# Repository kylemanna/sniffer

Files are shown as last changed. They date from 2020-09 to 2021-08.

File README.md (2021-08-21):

# Sniffer



Air quality sensor integration board that couples together the following modules:

- ESP32 TTGO T-Display module
- PMSA003 module
- BME680 CJMCU module

I use this to track the AQI in my home.  This sensor measures within 1% of 3x different [PurpleAir sensors
scattered around my
neighborhood](https://www.purpleair.com/map?opt=1/i/mAQI/a10/cC0#12.69/37.74937/-122.43828).  The PMSA003 particulate air sensor module in this build should be an
improved version the PMS5003 found in the [PurpleAir
sensors](https://www2.purpleair.com/collections/air-quality-sensors).

Combined with [Home Assistant](https://www.home-assistant.io/), [InfluxDB](https://www.influxdata.com/),
and [Grafana](https://grafana.com/) I can track the long term air quality inside and outside my home.

## Details

* [Blog post with more details](https://blog.kylemanna.com/hardware/sniffer-air-quality-monitor-aqi-using-esp32-pmsa003-bme680/)

## Order PCBs

Want to build one?

[Visit the shared project on PCBWay for direct ordering](https://www.pcbway.com/project/shareproject/Sniffer_Air_Quality_Monitor.html).

## Early PCB Assembly

Sniffer LCD Display

[Google Photos Image
Gallery](https://photos.google.com/share/AF1QipN3LYySqBTejioxieJ7yeqid8oVPh8rAkidfJqBqCnVjT7ktObNcwMXL6851PJW0A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)

## TODO

### Hardware

- [x] Design Kicad schematic + PCB
- [x] Release Gerbers
- [x] Order PCBs from [PCBWay (use my referral code "3549" to save $5)](https://www.pcbway.com/setinvite.aspx?inviteid=3549)
- [x] Photograph real PCB + PCBA

- [ ] Add pin labels to silk screen
- [ ] Route out hole for TTGO T-Display battery connector so it fits flatter
- [ ] Find someone to make a 3D printable enclosure

### Software

- [x] Upload ESPHome YAML file

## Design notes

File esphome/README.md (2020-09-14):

# ESPHome

ESPHome works great on the TTGO ESP32 T-Display and has drivers for all the necessary pieces.  Connect it
to HomeAssistant and let HomeAssistant log to InfluxDB and visualize long-term data with Grafana.

## Building And Flashing the Unit

### Step 1: Launch ESPHome Docker container with USB support

    docker run --name esphome --rm -it --network host --privileged -v /dev:/dev -v $PWD:/config esphome/esphome

Display support was added in ESPHome v1.15.0, but if you need dev features (docs at [next.esphome.io](https://next.esphome.io/)):

    docker run --name esphome --rm -it --network host --privileged -v /dev:/dev -v $PWD:/config esphome/esphome:dev

### Step 2: Load Web UI

Should be http://localhost:6052 by default

### Step 3: Create

Copy contents of `sniffer.template.yaml` into ESPHome `sniffer0.yaml` or similar.

Update the secrets file appropriately or use the provided template as a starting point.

### Step 4: Flash ESP32

Attach to USB port of system running the ESP32 Docker container and Upload the newly created config.

### Step 5: Iterations

Now you can run the Docker container without `--privileged -v /dev:/dev` as the over-the-air update will
work.

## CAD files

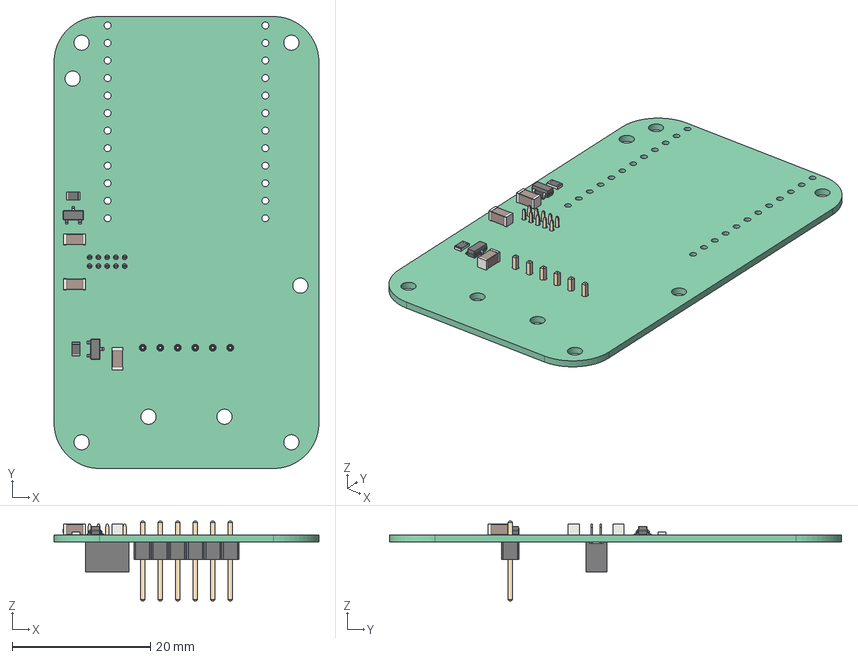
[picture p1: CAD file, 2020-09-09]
kicad/mechanicals/sniffer.step
38.4 x 65.5 x 11.5 mm
Local_CS_cf72
Pcb_cf72
PCB_Sketch_cf72
C1_C_1206_3216Metric_5F537C55
C2_C_1206_3216Metric_5F537BB3
C3_C_1206_3216Metric_5F537BE3
Q1_SOT_23_5F5360C2
Q2_SOT_23_5F537B45
R1_R_0805_2012Metric_5F53A661
R2_R_0805_2012Metric_5F537C13
J1_PinHeader_1x06_P254mm_Vertical_5F53974B
J2_PinSocket_2x05_P127mm_Vertical_5F536015

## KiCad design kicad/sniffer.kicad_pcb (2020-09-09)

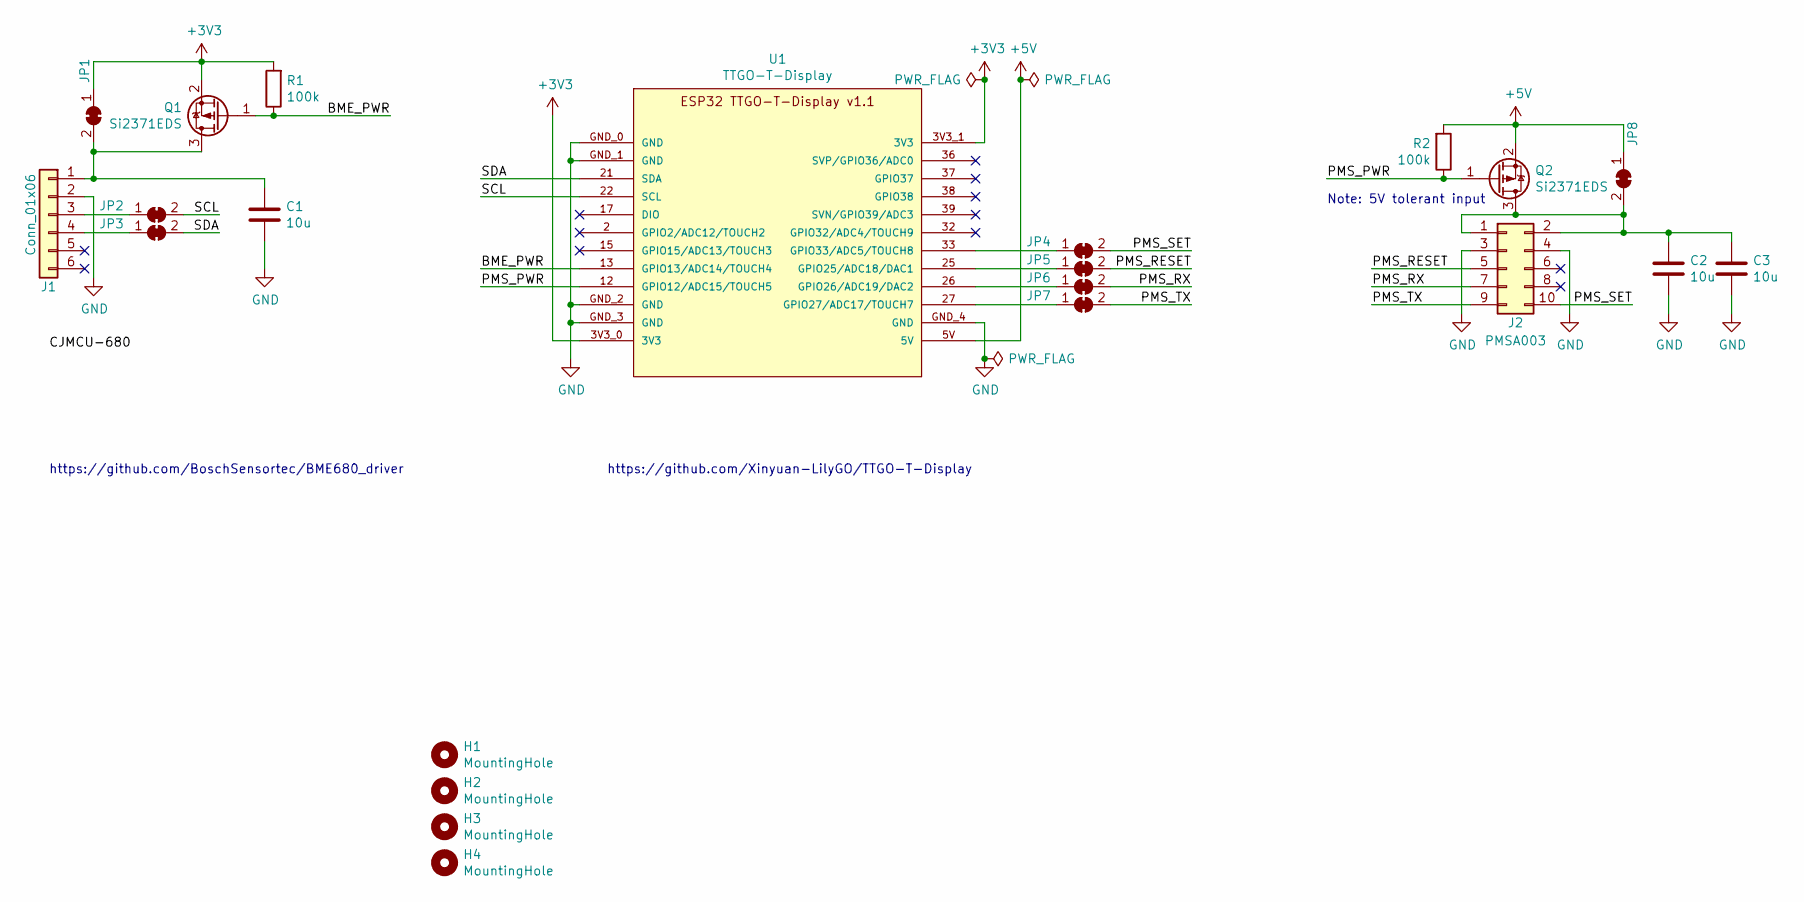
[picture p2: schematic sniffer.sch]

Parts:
C1, C2, C3: 10u; C_1206_3216Metric_Pad1.42x1.75mm_HandSolder
H1, H2, H3, H4: MountingHole; MountingHole_2.2mm_M2
J1: Conn_01x06; CJMCU-680
J2: PMSA003
JP1, JP2, JP3, JP4, JP5, JP6, JP7, JP8: SolderJumper_2_Bridged; SolderJumper-2_P1.3mm_Bridged_RoundedPad1.0x1.5mm
Q1, Q2: Si2371EDS; SOT-23
R1, R2: 100k; R_0805_2012Metric_Pad1.15x1.40mm_HandSolder
U1: TTGO-T-Display; TTGO-T-DISPLAY-OL-2

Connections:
+3V3: JP1.1 (A), Q1.2 (S), R1.2, U1.3V3_0 (3V3), U1.3V3_1 (3V3)
+5V: JP8.1 (A), Q2.2 (S), R2.2, U1.5V
/BME_PWR: Q1.1 (G), R1.1, U1.13 (GPIO13/ADC14/TOUCH4)
/PMS_PWR: Q2.1 (G), R2.1, U1.12 (GPIO12/ADC15/TOUCH5)
/PMS_RESET: J2.5, JP5.2 (B)
/PMS_RX: J2.7, JP6.2 (B)
/PMS_SET: J2.10, JP4.2 (B)
/PMS_TX: J2.9, JP7.2 (B)
/SCL: JP2.2 (B), U1.22 (SCL)
/SDA: JP3.2 (B), U1.21 (SDA)
GND: C1.2, C2.2, C3.2, J1.2, J2.3, J2.4, U1.GND_0 (GND), U1.GND_1 (GND), U1.GND_2 (GND), U1.GND_3 (GND), U1.GND_4 (GND)
unnamed: C1.1, J1.1, JP1.2 (B), Q1.3 (D)
unnamed: C2.1, C3.1, J2.1, J2.2, JP8.2 (B), Q2.3 (D)
unnamed: J1.3, JP2.1 (A)
unnamed: J1.4, JP3.1 (A)
unnamed: JP4.1 (A), U1.33 (GPIO33/ADC5/TOUCH8)
unnamed: JP5.1 (A), U1.25 (GPIO25/ADC18/DAC1)
unnamed: JP6.1 (A), U1.26 (GPIO26/ADC19/DAC2)
unnamed: JP7.1 (A), U1.27 (GPIO27/ADC17/TOUCH7)

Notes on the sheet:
https://github.com/Xinyuan-LilyGO/TTGO-T-Display
https://github.com/BoschSensortec/BME680_driver
Note: 5V tolerant input

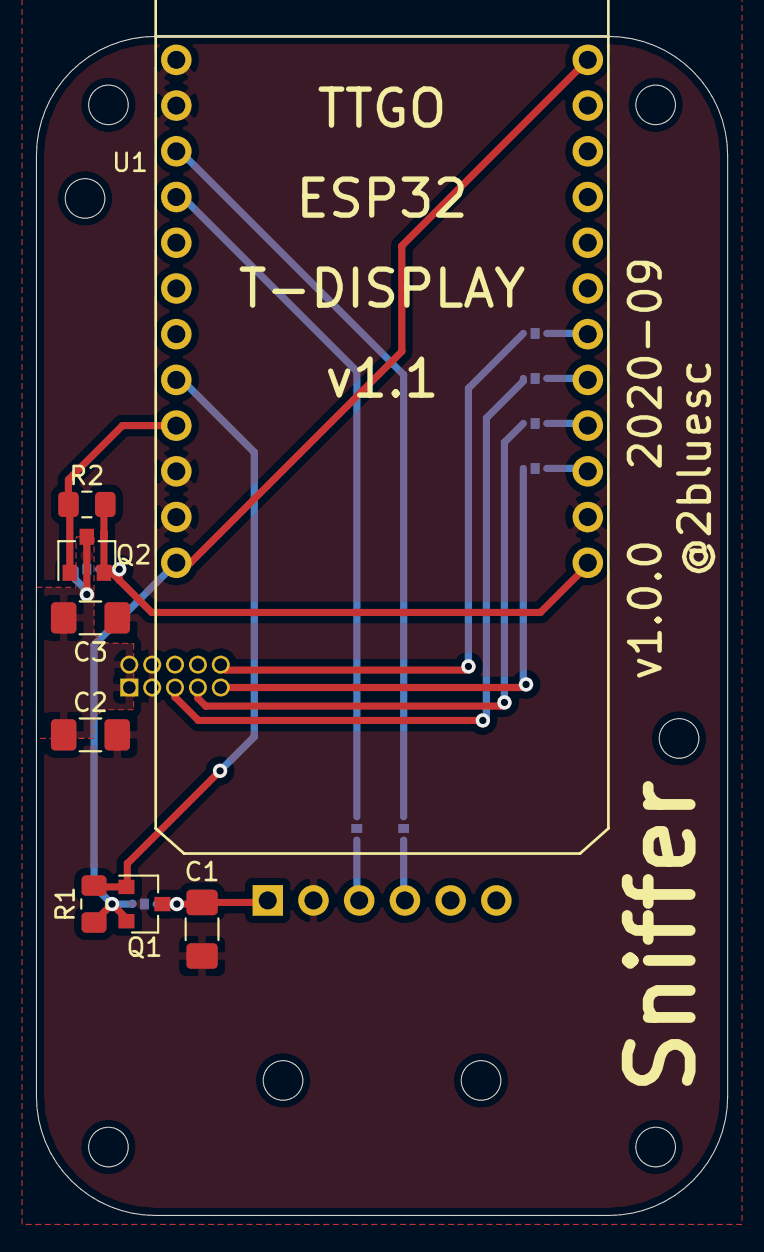
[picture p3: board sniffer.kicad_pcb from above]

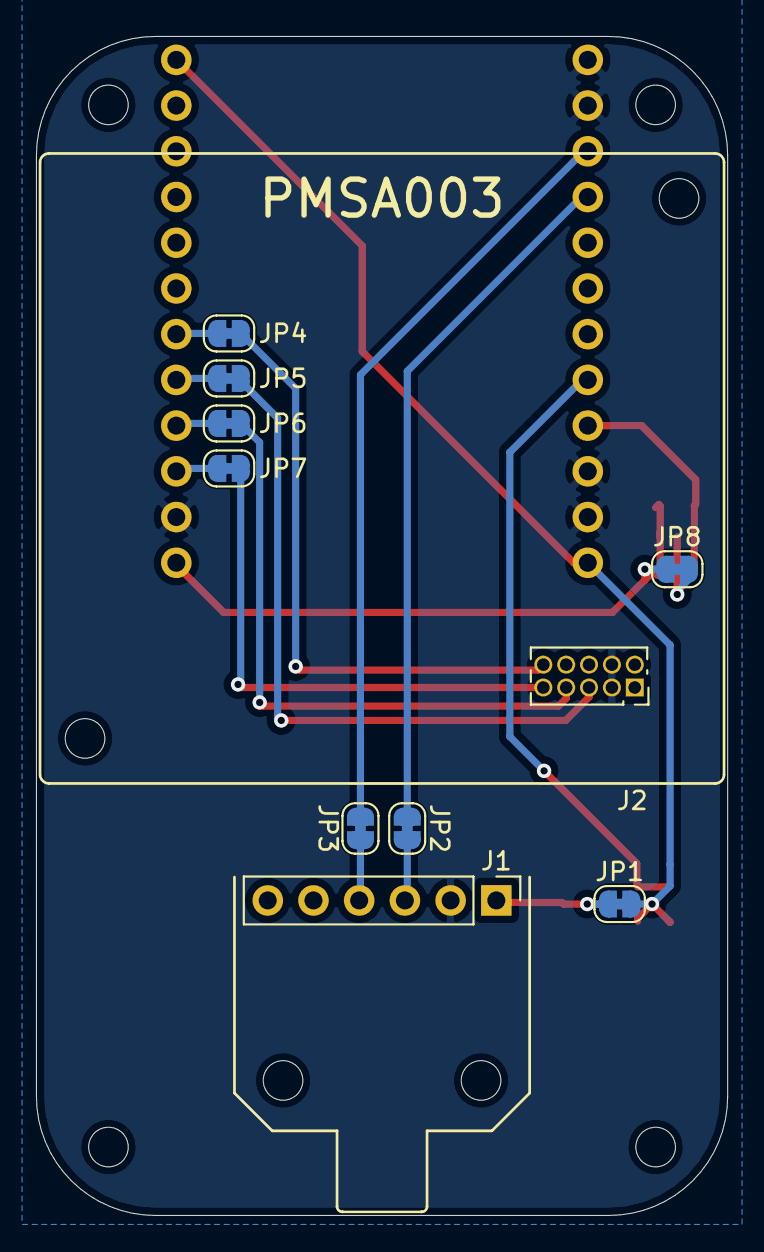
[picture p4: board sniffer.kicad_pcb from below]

Board: 2 copper layers, 38.4 x 65.5 mm, 22 parts (10 on the bottom side), 19 nets.

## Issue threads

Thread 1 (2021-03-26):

TTGO and PCB spacing

mckochan, 2021-03-26:
To anyone that has assembled one of these:
From the pictures, it looks like the TTGO either didn't have the battery connector or you removed it to allow the boards to sit close enough to use just the spacers on the male header pins?

Is there spacers available that I can use to raise the TTGO or does the battery connector removed easily?

Thanks in advance for this awesome project!

kylemanna, 2021-03-26:
I mounted the headers so they are slightly raised above the PCB to clear the battery connector.

For example if you took something small (toothpicks?) and put it in under the headers when you solder the 0.1" headers it'll solve the problem. Remove the toothpick (or whatever) after soldering.  I think I actually use a spare PCB from one side to hold the header at a consistent height.

See picture:
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

mckochan, 2021-03-26:
AH toothpick, genius! Thanks

Closed 2021-03-26.

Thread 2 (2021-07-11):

High temp value

Ralphy140, 2021-07-11:
comparing the value of other sensors sitting next to the Sniffer they seem to over read by 2-3C I suspect that this might be caused by the internal VOC sensor being on all the time as opposed to taking a sample every 60 seconds though i may be wrong.

In regards to the VOC and Air quality i have also found this that indicates how to extract the Bosch drivers to derive the VOC air quality

https://community.bosch-sensortec.com/t5/MEMS-sensors-forum/BME680-on-ESPHome-using-Bosch-s-BSEC-library/td-p/13210

I am no programmer but perhaps this could be updated into the code?

kylemanna, 2021-07-13:
I've noticed this as well and fear it may be higher then 3°C and have observed the same with the BME280 (no VOC sensor). I think it's actually being heated by the ESP32 through the pins.

I think the proper solution is to better isolate the BME680/280 better with a thermal PCB cutout or an external temp sensor like the [DS18B20](https://esphome.io/components/sensor/dallas.html?highlight=ds18b20)

I think the best workaround for this is to modify the esphome yaml code to provide a filter to subtract a 3°C offset or a more advanced function as I'm sure it's not a constant temperature offset.

Here's some documentation if you want to give it a try:
https://esphome.io/components/sensor/index.html#sensor-filters

Another option may be to reduce the power consumption of the ESP32 so it generates less heat, but I haven't looked to that yet.

Let me know if you get a chance to experiment with it!

kylemanna, 2021-07-13:
Another experiment would be to remove the BME680 from the pin headers and to attach it using wires that provide a poor thermal conduction path to see if this validates the idea.

Ralphy140, 2021-07-13:
Hey,

I have updated the YAML to make the required changes to take advantage of the VOC components and also reduce the temp by 3C, Happy to make a pull request or send it thought to you if you would like?

Ralphy140, 2021-07-13:
Also it seems odd that it exactly 3C across your ones and the 3 that i have made,

Ralphy140, 2021-07-16:
Pull request created to update temp off-set and BME680 driver

Closed 2021-07-16.

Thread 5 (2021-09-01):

Header for PMSA003

victorhooi, 2021-09-01:
I'm trying to locate an appropriate PMSA003 module to build this project.

In your [blog post](https://blog.kylemanna.com/hardware/sniffer-air-quality-monitor-aqi-using-esp32-pmsa003-bme680/
), you mention that the headers should be included with the modules, which you then solder to the PCB

I'm looking at some examples of the module (e.g. [here](https://www.aliexpress.com/item/32791143314.html
) and [here](https://www.aliexpress.com/item/32820384671.html)), and it's not always clear if the header is included.

Do you know of any reputable vendors that have the module with header? Or if not, where can you get the header from?

Ralphy140, 2021-09-01:
This one ships with the headers, the little black box with pins.

https://www.aliexpress.com/item/33024273311.html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

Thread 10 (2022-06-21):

TTGO chip update

larrygoodstuff, 2022-06-21:
It looks like the TTGO boards with a CP2104 chips are no longer available. They are only now available with a CH9102F chip. After successfully putting one together 1+ years ago, I decided to do another 4 and bought the components. After soldering them together and powering up I just get an "SDcard mount fail" error.

Will the pinouts need to change with the updated chip?

Awesome little project by the way.

hexonMD, 2024-01-20:
I ended up doing the same thing :(

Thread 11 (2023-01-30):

How do I upload the files to the TTGO?

zirdum, 2023-01-30:
Are there instructions on how to upload the yaml to the TTGO device?

Ralphy140, 2023-01-30:
This project uses ESPHome - https://esphome.io/ check out the getting started on the home page, It works really well with Home Assistant and would recommend you read up on that to get started.

Just to be clear you dont "upload" the YMAL to the device, you use a tool called ESP home that turns the YAML into a compiled file that is then uploaded to the esp32, you never upload the yaml directly to the device, if you want to change it you need to re-complie it in esphome then re-upload the file

zirdum, 2023-01-31:
Thank you. I figured out how to compile the yaml and uploaded it successfully to the ESP32.

Closed 2023-01-31.

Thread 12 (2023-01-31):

Pin connections between ESP32 and PMSA003

zirdum, 2023-01-31:
Hi,

I don't have the PCB yet, but I wanted to connect what I have to test things out first.

I have the esp32 wired to the PMSA003 with a G7-G135 connector in between (to make it easier to connect the wires)... I'm hoping it should work, but I can only go off of what the picture shows and it's very blurry (and I don't know how to read the schematics yet).

The G7-G135 adapter connected to the PMSA003 shows the wiring to be:
nc
nc
rst
tx
rx
set
gnd
vcc

With the power connector facing the left side (when looking at the esp32 and the display), I can see the vcc goes to the 1st pin on the bottom left of the ESP32 (5V), gnd goes to the 2nd pin from the bottom left (G) and I think set goes to the 3rd pin from the bottom left (pin 27). But it seems there are 2 pins from the PMSA003 are connected to each other perhaps (or do they go somewhere on the ESP32)?

Thank you.
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

Closed 2023-02-01.

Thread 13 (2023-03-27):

RecursionError: maximum recursion depth exceeded while calling a Python object

PureRandomGit, 2023-03-27:
When I run `esphome run sniffer0.yaml` I get this error: `RecursionError: maximum recursion depth exceeded while calling a Python object`. I have done all the steps as you have instructed in the README but it still doesn't work I have tried this on windows and Linux but to no avail. I also tried using the web UI, the manual installation, and ESPhome in homeassistant but none worked.

PureRandomGit, 2023-03-29:
The problem was solved by trying a fresh install and by using esphome through the command line. For anyone else having problems installing/compiling this first make sure that the esp board is flashed with the correct drivers, then if you receive an error about font or temp2 comment out the font and display section in sniffer_common (this makes the screen useless but I couldn't figure out what was wrong, if someone knows please let me know.)

Closed 2023-03-29.

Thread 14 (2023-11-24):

3D Printed Enclosure

raptor464, 2023-11-24:
I created a 3D print enclosure for this project. I actually made two of these sniffers. I'm thinking about uploading the files to Thingiverse. Let me know if you are interested in the STL files.
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

kylemanna, 2023-11-28:
Nice! Love to see it and thanks for sharing.  If you do upload it, please LMK so I can add links!

raptor464, 2023-12-03:
I put it up on Thingiverse:

https://www.thingiverse.com/thing:6348428

duceduc, 2024-08-02:
Hi. Are you willing to sell them and ship it internationally? Also, I bought another kit to have it place outside my balcony. Any chance of creating another case for outside conditions? I don't need the lcd to be visible. Let me know Thanks .

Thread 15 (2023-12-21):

Pin 4 Used in Multiple Places

bepstein111, 2023-12-21:
Unsure if this is a bug that ESPHome introduced, but when I went to update my sniffer with a new version, it complained that "Pin 4 is used in multiple places," both in as a gpio switch and as the backlight pin for the st7789v. Are you aware of this?

Ralphy140, 2023-12-22:
This is a new feature to stop misconfiguration where you reuse a pin by accident, It seems that this might be an edge case they have not captured in the feature release of 2023.12

Ralphy140, 2023-12-22:
Seems like someone has lodged a bug for this and the answer is to add Add "allow_other_uses: true"

I have not updated to 2023.12 yet but I would suggest adding it to the switch and see what happens

Ralphy140, 2023-12-22:
switch:
  - platform: gpio
    pin: GPIO4
    name: "${upper_devicename} Backlight"
    id: backlight
    restore_mode: ALWAYS_ON
    allow_other_uses: true"

bepstein111, 2023-12-22:
`[allow_other_uses] is an invalid option for [switch.gpio]. Please check the indentation.`

hmmmm

Ralphy140, 2023-12-27:
Ok had a play, The code needs to be updated as following

'''
switch:
  - platform: gpio
    pin:
      number: GPIO4
      allow_other_uses: true
    name: "${upper_devicename} Backlight"
    id: backlight
    restore_mode: ALWAYS_ON'''

and

'''
    backlight_pin:
      number: GPIO4
      allow_other_uses: true'''

Ralphy140, 2023-12-27:
This will need to be rolled into the main code by @kylemanna going forward

bepstein111, 2023-12-29:
Yep, just figured this out myself, they finally seem to have added it to the documentation.
For reference: https://esphome.io/guides/configuration-types.html?highlight=allow_other_uses#pin-schema

bepstein111, 2024-01-02:
I'll throw a pull request together.

Closed 2023-12-29.

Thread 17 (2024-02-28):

Sniffer used to work fine but after one of the recent updates it stalls out after time.

God-TM, 2024-02-28:
I've noticed lately that the sniffer stops working after running for a while.

It'll still respond over the network and I can in theory update it, etc. But when I connect into it, the logs show the PM2.5 is reporting with 0 constantly:
```
[10:11:13][W][component:214]: Component display took a long time for an operation (0.09 s).
[10:11:13][W][component:215]: Components should block for at most 20-30ms.
[10:11:13][D][pmsx003:236]: Got PM1.0 Concentration: 0 µg/m^3, PM2.5 Concentration 0 µg/m^3, PM10.0 Concentration: 0 µg/m^3
[10:11:14][W][component:214]: Component display took a long time for an operation (0.09 s).
[10:11:14][W][component:215]: Components should block for at most 20-30ms.
[10:11:14][D][pmsx003:236]: Got PM1.0 Concentration: 0 µg/m^3, PM2.5 Concentration 0 µg/m^3, PM10.0 Concentration: 0 µg/m^3
[10:11:15][D][pmsx003:236]: Got PM1.0 Concentration: 0 µg/m^3, PM2.5 Concentration 0 µg/m^3, PM10.0 Concentration: 0 µg/m^3

```
In Home Assistant I can see the temperature among other stats (pressure, wifi signal, etc.) are still updating... it's just the PM/AQI stuff that goes to 0 and then stays there:
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

If I physically reboot the device, AQI starts showing again. But after a day or so, it'll eventually go back to 0 and stay there. Any idea what could be going on?

Thank you.

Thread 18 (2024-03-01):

New issues due to ESPhome updates

jruben4, 2024-03-01:
sniffer_common has errors now with the new version of ESPhome due to the new way ESPhome wants you to program shared pins (pins defined in more than one place).

Ralphy140, 2024-03-01:
Has been resolved in issue 15 and new code has been merged into this repo

jruben4, 2024-03-01:
Trying the new code.  Getting error "Couldn't find ID 'temp2'." in sniffer_common.

michaellunzer, 2024-04-27:
hey @jruben4 same "temp2" error here. any suggestions?

jruben4, 2024-04-27:
> hey @jruben4 same "temp2" error here. any suggestions?

Yes, I edited sniffer_common.yaml to take out all the temp2 references.  Here it is:

`esphome:
  name: $devicename
  platform: ESP32
  board: featheresp32

wifi:
  ssid: !secret wifi_ssid
  password: !secret wifi_password

  # Enable fallback hotspot (captive portal) in case wifi connection fails
  ap:
    ssid: "${upper_devicename} Hotspot"
    password: "lost_sniffuh"

captive_portal:

# Enable logging
logger:

# Enable Home Assistant API
api:
  encryption:
    key: !secret ha_api_key

ota:
  password: !secret ota_password

color:
  - id: my_red
    red: 100%
    green: 0%
    blue: 0%
  - id: my_yellow
    red: 100%
    green: 100%
    blue: 0%
  - id: my_green
    red: 0%
    green: 100%
    blue: 0%
  - id: my_blue
    red: 0%
    green: 0%
    blue: 100%
  - id: my_gray
    red: 50%
    green: 50%
    blue: 50%

# Grab font from https://fonts.google.com/specimen/Roboto and place in same directory as this file
font:
  - file: "Roboto-Medium.ttf"
    id: sz_24
    size: 24
  - file: "Roboto-Medium.ttf"
    id: sz_20
    size: 20
    glyphs: '!"%()+,-_.:°0123456789ABCDEFGHIJKLMNOPQRSTUVWXYZ abcdefghijklmnopqrstuvwxyz/³µΩ'
  - file: "Roboto-Medium.ttf"
    id: sz_13
    size: 13

binary_sensor:
  - platform: status
    name: "${upper_devicename} Node Status"
    id: system_status
  - platform: gpio
    pin:
      number: GPIO0
      inverted: true
      mode: INPUT_PULLUP
    name: "${upper_devicename} Button S1"
    id: button0
    on_press:
      then:
        - switch.toggle: backlight

  - platform: gpio
    pin:
      number: GPIO35
      inverted: true
    name: "${upper_devicename} Button S2"
    id: button1
    on_press:
      then:
        - switch.toggle: backlight

switch:
  - platform: gpio
    pin:
      number: GPIO4
      allow_other_uses: true
    name: "${upper_devicename} Backlight"
    id: backlight
    restore_mode: ALWAYS_ON

time:
  - platform: homeassistant
    id: esptime
    timezone: America/Los_Angeles

spi:
  clk_pin: GPIO18
  mosi_pin: GPIO19

display:
  - platform: st7789v
    model: TTGO TDisplay 135x240
    backlight_pin:
      number: GPIO4
      allow_other_uses: true
    cs_pin: GPIO5
    dc_pin: GPIO16
    reset_pin: GPIO23
    update_interval: 1s
    rotation: 270
    lambda: |-
      it.rectangle(0,  0, it.get_width(), it.get_height(), id(my_blue));
      it.rectangle(0, 19, it.get_width(), it.get_height(), id(my_blue));   // header bar

      it.strftime(4,  3, id(sz_13), id(my_yellow), TextAlign::TOP_LEFT, "%Y-%m-%d %H:%M:%S", id(esptime).now());

      if (id(system_status).state) {
        it.print(236, 3, id(sz_13), id(my_green), TextAlign::TOP_RIGHT, "${upper_devicename} Online");
      } else {
        it.print(236, 3, id(sz_13), id(my_red), TextAlign::TOP_RIGHT, "${upper_devicename} Offline");
      }

      int r = 18;

      it.print(4,    r, id(sz_24), id(my_gray),   TextAlign::TOP_LEFT,  "PM2.5:");

      auto color = id(my_red);
      if (id(pm_2_5_aqi).state < 50) color = id(my_green);
      else if (id(pm_2_5_aqi).state < 100) color = id(my_yellow);
      it.printf(236, r, id(sz_24), color, TextAlign::TOP_RIGHT, "%0.0f AQI", id(pm_2_5_aqi).state);

      r += 21;
      it.print(4,    r, id(sz_20), id(my_gray),   TextAlign::TOP_LEFT,  "PM:");
      it.printf(236, r, id(sz_20), id(my_yellow), TextAlign::TOP_RIGHT, "%0.0f/%0.0f/%0.0f µg/m³", id(pm_1_0).state, id(pm_2_5).state, id(pm_10).state);

      r += 25;
      it.print(120,    r, id(sz_24), id(my_gray),   TextAlign::TOP_CENTER,  "Environment");

      r += 23;
      float temp_f = id(temp).state * (9.0/5.0) + 32.0;
      /*float temp2_f = id(temp2).state * (9.0/5.0) + 32.0;*/
      /*it.printf(4,   r, id(sz_20), id(my_yellow), TextAlign::TOP_LEFT, "%0.1f°F", id(temp).state); */
      it.printf(4,   r, id(sz_20), id(my_yellow), TextAlign::TOP_LEFT, "%0.1f°F", temp_f);
      /*it.printf(125, r, id(sz_24), id(my_yellow), TextAlign::TOP_CENTER, "%0.1f°F", temp2_f);*/
      it.printf(236, r, id(sz_20), id(my_yellow), TextAlign::TOP_RIGHT,  "%0.1f%%", id(humidity).state);

      r += 21;
      it.printf(4,   r, id(sz_20), id(my_yellow), TextAlign::TOP_LEFT,  "%0.1f hPa", id(pressure).state);
      it.printf(236, r, id(sz_20), id(my_yellow), TextAlign::TOP_RIGHT, "%0.1f kΩ",  id(gas_resistance).state/1000.0);

# Particulate matter configuration entry
uart:
  rx_pin: GPIO27
  baud_rate: 9600

# For temp + humidity sensor
i2c:
  sda: 21
  scl: 22
  scan: True
  id: bus_a

sensor:
  - platform: pmsx003
    id: pmsa003
    type: PMSX003

    pm_1_0:
      id: pm_1_0
      name: "${upper_devicename} PM <1.0 µm"
      filters:
      - sliding_window_moving_average:
          window_size: 30
          send_every: 10

    pm_2_5:
      id: pm_2_5
      name: "${upper_devicename} PM <2.5 µm"
      filters:
      - sliding_window_moving_average:
          window_size: 30
          send_every: 10
      on_value:
        lambda: |-
          // https://en.wikipedia.org/wiki/Air_quality_index#Computing_the_AQI
          if (id(pm_2_5).state < 12.0) {
            // good
            id(pm_2_5_aqi).publish_state((50.0 - 0.0) / (12.0 - 0.0) * (id(pm_2_5).state - 0.0) + 0.0);
          } else if (id(pm_2_5).state < 35.4) {
            // moderate
            id(pm_2_5_aqi).publish_state((100.0 - 51.0) / (35.4 - 12.1) * (id(pm_2_5).state - 12.1) + 51.0);
          } else if (id(pm_2_5).state < 55.4) {
            // usg
            id(pm_2_5_aqi).publish_state((150.0 - 101.0) / (55.4 - 35.5) * (id(pm_2_5).state - 35.5) + 101.0);
          } else if (id(pm_2_5).state < 150.4) {
            // unhealthy
            id(pm_2_5_aqi).publish_state((200.0 - 151.0) / (150.4 - 55.5) * (id(pm_2_5).state - 55.5) + 151.0);
          } else if (id(pm_2_5).state < 250.4) {
            // very unhealthy
            id(pm_2_5_aqi).publish_state((300.0 - 201.0) / (250.4 - 150.5) * (id(pm_2_5).state - 150.5) + 201.0);
          } else if (id(pm_2_5).state < 350.4) {
            // hazardous
            id(pm_2_5_aqi).publish_state((400.0 - 301.0) / (350.4 - 250.5) * (id(pm_2_5).state - 250.5) + 301.0);
          } else if (id(pm_2_5).state < 500.4) {
            // hazardous 2
            id(pm_2_5_aqi).publish_state((500.0 - 401.0) / (500.4 - 350.5) * (id(pm_2_5).state - 350.5) + 401.0);
          }

    pm_10_0:
      id: pm_10
      name: "${upper_devicename} PM <10.0 µm"
      filters:
      - sliding_window_moving_average:
          window_size: 30
          send_every: 10

  - platform: template
    name: "${upper_devicename} PM <2.5 AQI"
    unit_of_measurement: "AQI"
    icon: "mdi:air-filter"
    accuracy_decimals: 0
    id: pm_2_5_aqi

  - platform: wifi_signal
    name: "${upper_devicename} WiFi Signal"`

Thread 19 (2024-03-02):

Failed config on sniffer.common.yaml during setup

hexonMD, 2024-03-02:
INFO ESPHome 2024.2.1
INFO Reading configuration /config/esphome/ttgo.yaml...
WARNING GPIO0 is a strapping PIN and should only be used for I/O with care.
Attaching external pullup/down resistors to strapping pins can cause unexpected failures.
See https://esphome.io/guides/faq.html#why-am-i-getting-a-warning-about-strapping-pins
WARNING GPIO5 is a strapping PIN and should only be used for I/O with care.
Attaching external pullup/down resistors to strapping pins can cause unexpected failures.
See https://esphome.io/guides/faq.html#why-am-i-getting-a-warning-about-strapping-pins
Failed config

display.st7789v: [source /config/esphome/sniffer_common.yaml:107]
  platform: st7789v
  model: TTGO_TDISPLAY_135X240
  backlight_pin:
    number: 4
    allow_other_uses: True
    mode:
      output: True
      input: False
      open_drain: False
      pullup: False
      pulldown: False
    inverted: False
    ignore_strapping_warning: False
    drive_strength: 20.0
  cs_pin:
    number: 5
    mode:
      output: True
      input: False
      open_drain: False
      pullup: False
      pulldown: False
    inverted: False
    ignore_strapping_warning: False
    drive_strength: 20.0
  dc_pin:
    number: 16
    mode:
      output: True
      input: False
      open_drain: False
      pullup: False
      pulldown: False
    inverted: False
    ignore_strapping_warning: False
    drive_strength: 20.0
  reset_pin:
    number: 23
    mode:
      output: True
      input: False
      open_drain: False
      pullup: False
      pulldown: False
    inverted: False
    ignore_strapping_warning: False
    drive_strength: 20.0
  update_interval: 1s
  rotation: 270

  Couldn't find ID 'temp2'. Please check you have defined an ID with that name in your configuration. These IDs look similar: "temp".
  lambda: !lambda |-
    it.rectangle(0,  0, it.get_width(), it.get_height(), id(my_blue));
    it.rectangle(0, 19, it.get_width(), it.get_height(), id(my_blue));   // header bar

    it.strftime(4,  3, id(sz_13), id(my_yellow), TextAlign::TOP_LEFT, "%Y-%m-%d %H:%M:%S", id(esptime).now());

    if (id(system_status).state) {
      it.print(236, 3, id(sz_13), id(my_green), TextAlign::TOP_RIGHT, "Sniffer0 Online");
    } else {
      it.print(236, 3, id(sz_13), id(my_red), TextAlign::TOP_RIGHT, "Sniffer0 Offline");
    }

    int r = 18;

    it.print(4,    r, id(sz_24), id(my_gray),   TextAlign::TOP_LEFT,  "PM2.5:");

    auto color = id(my_red);
    if (id(pm_2_5_aqi).state < 50) color = id(my_green);
    else if (id(pm_2_5_aqi).state < 100) color = id(my_yellow);
    it.printf(236, r, id(sz_24), color, TextAlign::TOP_RIGHT, "%0.0f AQI", id(pm_2_5_aqi).state);

    r += 21;
    it.print(4,    r, id(sz_20), id(my_gray),   TextAlign::TOP_LEFT,  "PM:");
    it.printf(236, r, id(sz_20), id(my_yellow), TextAlign::TOP_RIGHT, "%0.0f/%0.0f/%0.0f µg/m³", id(pm_1_0).state, id(pm_2_5).state, id(pm_10).state);

    r += 25;
    it.print(120,    r, id(sz_24), id(my_gray),   TextAlign::TOP_CENTER,  "Environment");

    r += 23;
    float temp_f = id(temp).state * (9.0/5.0) + 32.0;
    float temp2_f = id(temp2).state * (9.0/5.0) + 32.0;
    /*it.printf(4,   r, id(sz_20), id(my_yellow), TextAlign::TOP_LEFT, "%0.1f°F", id(temp).state); */
    it.printf(4,   r, id(sz_20), id(my_yellow), TextAlign::TOP_LEFT, "%0.1f°F", temp_f);
    it.printf(125, r, id(sz_24), id(my_yellow), TextAlign::TOP_CENTER, "%0.1f°F", temp2_f);
    it.printf(236, r, id(sz_20), id(my_yellow), TextAlign::TOP_RIGHT,  "%0.1f%%", id(humidity).state);

    r += 21;
    it.printf(4,   r, id(sz_20), id(my_yellow), TextAlign::TOP_LEFT,  "%0.1f hPa", id(pressure).state);
    it.printf(236, r, id(sz_20), id(my_yellow), TextAlign::TOP_RIGHT, "%0.1f kΩ",  id(gas_resistance).state/1000.0);
  auto_clear_enabled: True
  eightbitcolor: False
  height: 240
  width: 135
  offset_height: 52
  offset_width: 40

Ralphy140, 2024-03-02:
Check issue 15 this has been resolved

Ralphy140, 2024-03-02:
You will need to remove the refrence to temp2 if you are not using the ds18b temp sensor package
```
      #float temp2_f = id(temp2).state * (9.0/5.0) + 32.0;
      /*it.printf(4,   r, id(sz_20), id(my_yellow), TextAlign::TOP_LEFT, "%0.1f°F", id(temp).state); */
      it.printf(4,   r, id(sz_20), id(my_yellow), TextAlign::TOP_LEFT, "%0.1f°F", temp_f);
      #it.printf(125, r, id(sz_24), id(my_yellow), TextAlign::TOP_CENTER, "%0.1f°F", temp2_f);
      it.printf(236, r, id(sz_20), id(my_yellow), TextAlign::TOP_RIGHT,  "%0.1f%%", id(humidity).state);

```

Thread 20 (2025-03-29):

New platform error with esphome

jruben4, 2025-03-29:
New format to ESPhome platform component.  Your sniffer_common.yaml needs to start like this now:

`esphome:
  name: $devicename

esp32:
  board: featheresp32`

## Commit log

2020-09-05 sync: First pass complete
    * Maybe ready for manufacture
    [sniffer.kicad_pcb, sniffer.sch]
2020-09-05 sync: Miscellaneous tweaks
    * Clean-up footprint mounting holes.
    * Move some references.
    * Add mounting holes to design.
    [sniffer.kicad_pcb, sniffer.sch]
2020-09-05 gerbers: First pass
    * Looks plausible.
    [sniffer-B_Cu.gbr, sniffer-B_Mask.gbr, sniffer-B_Paste.gbr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]
2020-09-05 repo: Move pcb files to kicad folder
    * Kicad today, ESPHome tomorrow.
    [sniffer-B_Cu.gbr, sniffer-B_Mask.gbr, sniffer-B_Paste.gbr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]
2020-09-07 readme: Add PCBWay Shared Project link
    * Easier to order.
2020-09-09 kicad: Update user origin and dimension holes
    * Simplifies mechanical design
    [sniffer.kicad_pcb]
2020-09-09 kicad: Add mechanical STEP file
    * Maybe assists enclosure design.
    * Generated using FreeCAD + Kicad StepUp module
    [sniffer.step]
2020-09-12 README: Add real photos of PCB assembly
    * One week later it's real.
2020-09-12 esphome: Fix Node Status and Backlight Sensor Entities
    * These were ambiguous in Home Assistance and manually enumerated.
    * Prefix with name as other entities are.
2020-09-13 esphome: Make toggle backlight fix names
    * Toggle backlight on button press
    * Clean-up whitespace
    * Make AQI name consistent with others
2020-09-14 esphome: bme680: Filter out spurious gas values
    * 1 Megaohm seems crazy.
2021-04-18 esphome: Add WiFi signal sensor
    * Track WiFi signal.
2021-11-07 ds18b20: Add basic external temperature sensor
    * External sensor has better accuracy
2023-03-25 sniffer: Fixes for 2023.3.1
    * Dallas sensor impacted by 2022.12 release which broke the sensor until
    a pull-up was added.
    * Pull up on GPIO12 breaks bootstrapping.
2026-07-16 sniffer: Update common ESPHome configuration
    - Migrate to the current ESPHome framework and display schema.
    - Replace the deprecated st7789v driver with mipi_spi.
    - Update PM2.5 AQI calculation and simplify entity names.

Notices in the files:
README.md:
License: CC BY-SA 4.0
